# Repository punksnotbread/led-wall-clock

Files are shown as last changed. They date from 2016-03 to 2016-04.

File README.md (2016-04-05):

# led-wall-clock
A fancy RGB LED matrix wall clock controlled by a Raspberry Pi.



# Parts List
- [64x32 RGB LED Matrix - 5mm pitch](https://www.adafruit.com/products/2277)
- [Adafruit RGB Matrix + Real Time Clock Hat](https://www.adafruit.com/product/2345)
- Raspberry Pi 2 Model B
- [Acrylic Mount Plate](http://www.ponoko.com/build-your-own/furniture/led-wall-clock-plate-13293#) ([with light sensor](http://www.ponoko.com/build-your-own/furniture/led-wall-clock-plate-rev2-13311))

# Dependencies
Python libraries
- [rpi-rgb-led-matrix](https://github.com/hzeller/rpi-rgb-led-matrix)
- requests
- apscheduler
- daemonify

# RGB Matrix Hat Modification
The brightness can be controlled by pulse-width-modulating the OE pin of the LED matrix.  Unfortunately, the hat does not have the PWM pin of the Raspberry Pi connected to the OE pin.  To correct this, jumper a wire between pins labeled 4 and 18 on the hat.

# RGB Matrix Library Build Instructions
Clone this repository and submodules to your Raspberry Pi
```
git clone --recursive https://github.com/jeffkub/led-wall-clock.git
cd led-wall-clock/rpi-rgb-led-matrix
```
Edit `lib/Makefile` and uncomment the following two DEFINES
```
# Uncomment the following line for Adafruit Matrix HAT gpio mappings.
# If you have an Adafruit HAT ( https://www.adafruit.com/products/2345 ),
# you need to use this option as the HAT swaps pins around that are not
# compatible with the default mapping.
DEFINES+=-DADAFRUIT_RGBMATRIX_HAT

# Uncomment if you want to use the Adafruit HAT with stable PWM timings.
# The newer version of this library allows for much more stable (less flicker)
# output, but it does not work with the Adafruit HAT unless you do a
# simple hardware hack on them:
# connect GPIO 4 (old OE) with 18 (the new OE); there are
# convenient solder holes labeled 4 and 18 on the Adafruit HAT, pretty
# close together.
# Then uncomment the following define and recompile.
DEFINES+=-DADAFRUIT_RGBMATRIX_HAT_PWM
```
Build and install the Python library
```
make build-python
sudo make install-python
```
# Starting the Clock
To start the clock as a daemon
```
cd led-wall-clock
sudo ./ledclock.py -d start
```
# To Do
- Use a more generic weather API
- Move configuration to a separate file
- Implement dimming based on TSL2591 light sensor
- Add forecast screen (toggle on a timer)

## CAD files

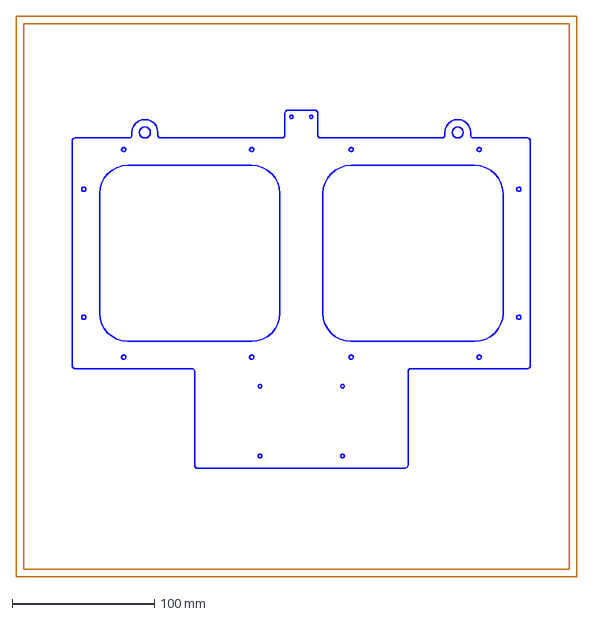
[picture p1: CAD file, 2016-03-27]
mount/WallClockMountPlate.dxf
394.0 x 394.0 mm

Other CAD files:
mount/MountPlateDrawing.dwg
mount/MountPlate.ipt

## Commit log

2016-03-27 Updated acrylic base to mount a Adafruit TSL2591 light sensor
    [MountPlate.ipt, MountPlateDrawing.dwg, WallClockMountPlate.dxf]
2016-04-05 Added git submodule for led matrix library
2016-04-05 Update README.md
    Updated README instructions to use git submodule for the led matrix library
2021-11-14 Scrape meteo for temperatures
